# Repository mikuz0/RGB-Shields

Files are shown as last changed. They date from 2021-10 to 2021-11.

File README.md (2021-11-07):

# RGB-Shields
<p>RGB(W) шильд предназначен для создания прототипов и конечных устройств по управлению светодиодным освещением, совместно с Arduino nano.</p> 
</br>
<b>Основные характеристики: </b>

Напряжение питания: 12 в(ограничено Arduino nano) 

Выходной ток: не более 3 А на канал. 

Суммарный ток нагрузок не более 3 А. 

Количество независимых каналов: 4

Количество кнопок управления: 3

Возможность подключения ИК приёмника: да (приемник ИК сигнала vs1838)

Возможность программного контроля напряжения питания: да. 

Размеры габаритные: 60х49 мм

Размеры под винт: 52х38,4

3D модель: ссылка тут

Надписи с адресами подключения цепей на плате позволяют упростить создание программного обеспечения.

Демо ПО:

Есть пример, демонстрирующий основные возможности RGB(W) шильда. (<a href="https://github.com/mikuz0/RGB-Shields/tree/main/3d-print/models " >ссылка тут </a>) 

Пример предназначен только для проверки исправности RGB(W) шильда. 

Назначение кнопок в демоПО:

1. Переход на следующий режим

2. Увеличить яркость

3. Уменьшить яркость

Режимы демоПО:

1. Проверка совместной работы каналов. 

2. Проверка работы канала R. Остальные каналы закрыты. 

3. Проверка работы канала G.  Остальные каналы полностью закрыты. 

4. Проверка работы канала B. Остальные каналы полностью закрыты. 

5. Проверка работы канала W. Остальные каналы полностью закрыты. 

<b>Схема подключения RGBW-shield и данные для разработки програмного обеспечения.</b> <br>
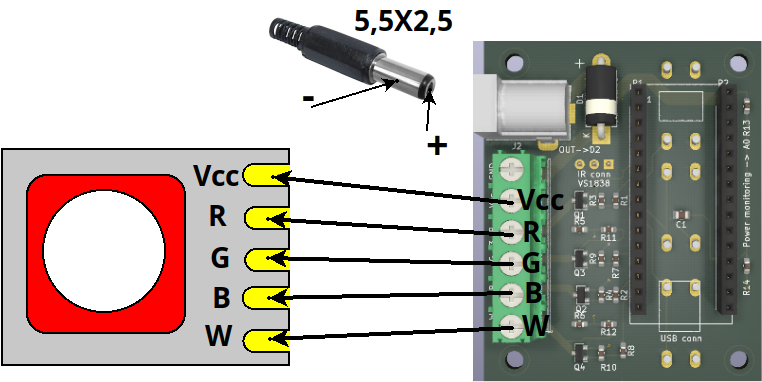
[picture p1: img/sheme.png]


<p>
Каналы R, G, B, W могут назначяться программно. В описании каналы обозначены в соответствии с предлагаемых ниже ПО. ПО не входит в поставку и предлагается как есть, без гарантий.
</p>

<p>
R - D3
</p>
<p>
G - D9
</p>
<p>
B - D10
</p>
<p>
W - D11
</p>

Каналы идентичный по нагрузочной способности.
VS1838 - D2
Кнопки D4, D5, D6  (см. маркировку на плате рядом с каждой кнопкой)

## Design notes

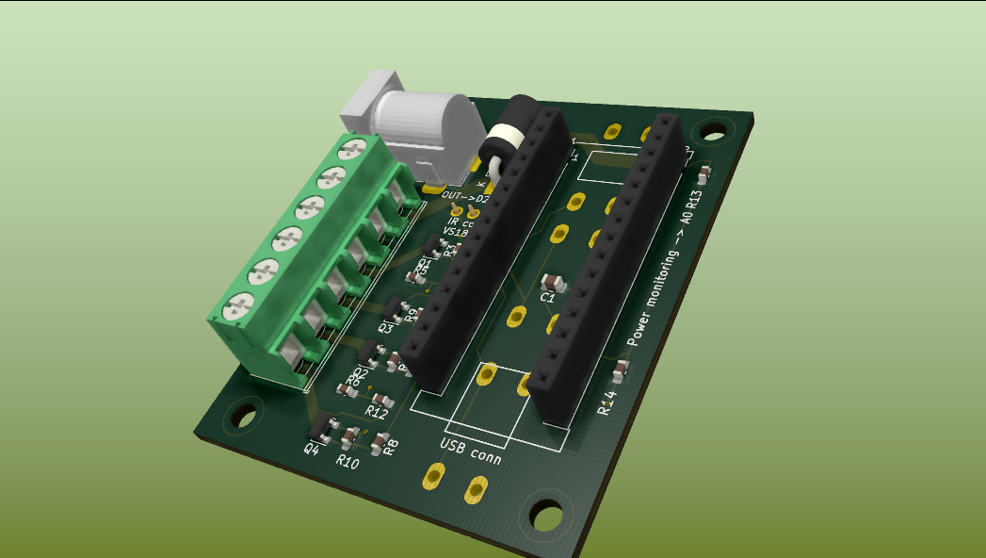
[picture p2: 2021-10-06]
screenshot_20210107_102106_0.png

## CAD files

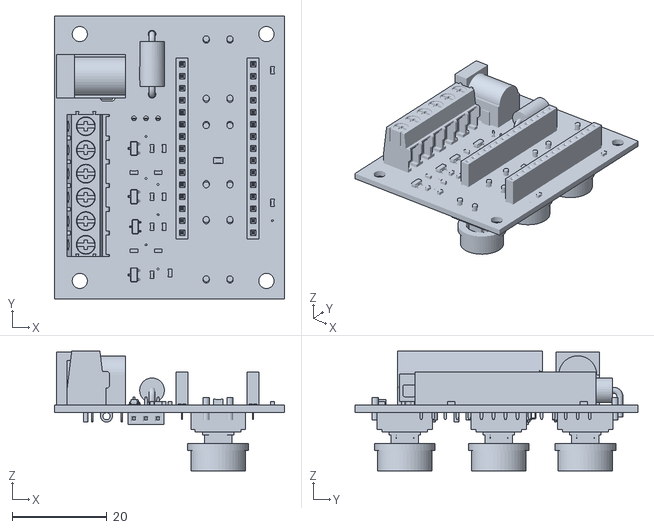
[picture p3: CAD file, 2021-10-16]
3d-print/ case/RGBschildSOT223.stl
48.5 x 59.7 x 25.3

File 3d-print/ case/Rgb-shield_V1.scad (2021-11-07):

//Enter OpenSCAD code here.
 echo("Version:",version());
r=100;
// Рисовать плату или нет.
PCB=1;
// размеры платы
A=48.26;
B=59.69;
H=25; //габаритная высота
S=1.5; // толщина текстолита
//размеры под винт
Av=39.37;
Bv=52.07;
Sm=5.5; // отступ отверстий от переднего края
Sb=3.81; // отступ отверстий с боков
//стойки для платы
Hp=7;
//толщина стенок
s=2;
//стойки для крышки
Ds=4;
Hs=H+s+S;
//размеры внутреннего объема
Aa=A+2;
Bb=B+2*Ds+2;

//радиус кнопки
Rp=6.5;
// Высота стоек под плату
Hss=11.6;
// стойка под крышку
module  rackb ( ) 
{ 

   
    difference() {
         union () {
cylinder (Hs, Ds/2, Ds/2, false, 
$fn=r);
     translate ([-s/3, -s/3, Hs/2+s/2]) 
 cube([Ds, Ds, Hs-s] , true, $fn=r);   
}       
        translate ([0, 0, 2*Hs/3]) 
  cylinder (Hs, 1.2, 1.2, false, 
$fn=r);      
    };

}
// стойка под плату
module  rack ( x=0,y=0) 
{   translate ([x, y, 0]) 
    difference() {
         
cylinder (Hss, Ds*0.8, 0.8*Ds, false, 
$fn=r);
    
      
        translate ([0, 0, 2*Hss/3]) 
  cylinder (Hss, 1.2, 1.2, false, 
$fn=r);      
    };

}

difference() {
union() 
{
 hull() {  translate([s, s, s])
  sphere(d=2*s, true, $fn=r);
   translate([Aa+2*s-s, s, s])
   sphere(d=2*s, true, $fn=r); 
   translate([Aa+2*s-s, Bb+2*s-s, s])
   sphere(d=2*s, true, $fn=r);  
     translate([s, Bb+2*s-s, s])
   sphere(d=2*s, true, $fn=r);  
    // Top
    translate([s, s, Hs])
   sphere(d=2*s, true, $fn=r);
   translate([Aa+2*s-s, s, Hs])
   sphere(d=2*s, true, $fn=r); 
 translate([Aa+2*s-s, Bb+2*s-s, Hs])
  sphere(d=2*s, true, $fn=r);  
   translate([s, Bb+2*s-s, Hs])
   sphere(d=2*s, true, $fn=r); 
  }

} ;
translate([s, s, s]) 
cube([Aa, Bb, Hs+4*s],$fn=r);

//отверстия под кнопки
Xk=34.18+0.42+s+0.5;
Yk=9.6+s+Ds+1+0.65;
Yk2=20.52;
translate ([Xk,Yk+Yk2+17.78,0])
cylinder (10, Rp, Rp, true, $fn=r);
translate ([Xk,Yk+Yk2,0])
cylinder (10, Rp, Rp, true, $fn=r);
translate ([Xk,Yk,0])
cylinder (10, Rp, Rp, true, $fn=r);
// Отверстия под питание
translate ([0,49.7,15])
cube([10, 10, 10],$fn=r);
translate ([0,19.7,20])
cube([10, 20, 5],$fn=r);
// отв. ИК приемник
translate ([s+0.5+16,Ds+s+1+27,0])
cube([6.1, 8.1, 10],$fn=r);
} 
// стойки для крышки
translate ([Ds/2+s, Ds/2+s, 0])
rackb ();
//rackb (0, 0, 0);
translate ([Aa-Ds/2+s, Ds/2+s, 0])
rotate([0,0,90]) 
rackb ();
translate ([Aa-Ds/2+s, Bb-Ds/2+s, 0])
rotate([0,0,180]) 
rackb ();
translate ([Ds/2+s, Bb-Ds/2+s, 0])
rotate([0,0,-90]) 
rackb ();

translate ([Sm+s+0.5,s+Sb+Ds+1,0]){
union (){
rack (0,0);
rack (0,52.07);
rack (39.37,52.07);
rack (39.37,0);
}
}
// Импорт платы
if (PCB==1)
    // 0.42 и 0.65 отступ 3 модели от нуля координат, 0.5 и 1 отступ от стенок
translate( [s+0.42+0.5, s+Ds+1+0.65, 12.5 ]){
difference () {
rotate([0,0,0]){#import ( "RGBschildSOT223.stl",  convexity = 5);}
 
 }
 }

// крышка
 module  vint ( x=0,y=0) 
{   translate ([x, y, -0.1]) 
    union() {
         
cylinder (s, 2.7, 0, false, 
$fn=r);
 
  cylinder (10, 1.6, 1.6, false, 
$fn=r);      
    };

}
 translate ([60,0,0])

 difference () {
cube([Aa-0.2, Bb-0.2, s],$fn=r);
vint (Ds, Ds);
vint (Aa-0.2-Ds, Ds);
vint (Aa-0.2-Ds, Bb-0.2-Ds);
vint (Ds, Bb-0.2-Ds);
 }

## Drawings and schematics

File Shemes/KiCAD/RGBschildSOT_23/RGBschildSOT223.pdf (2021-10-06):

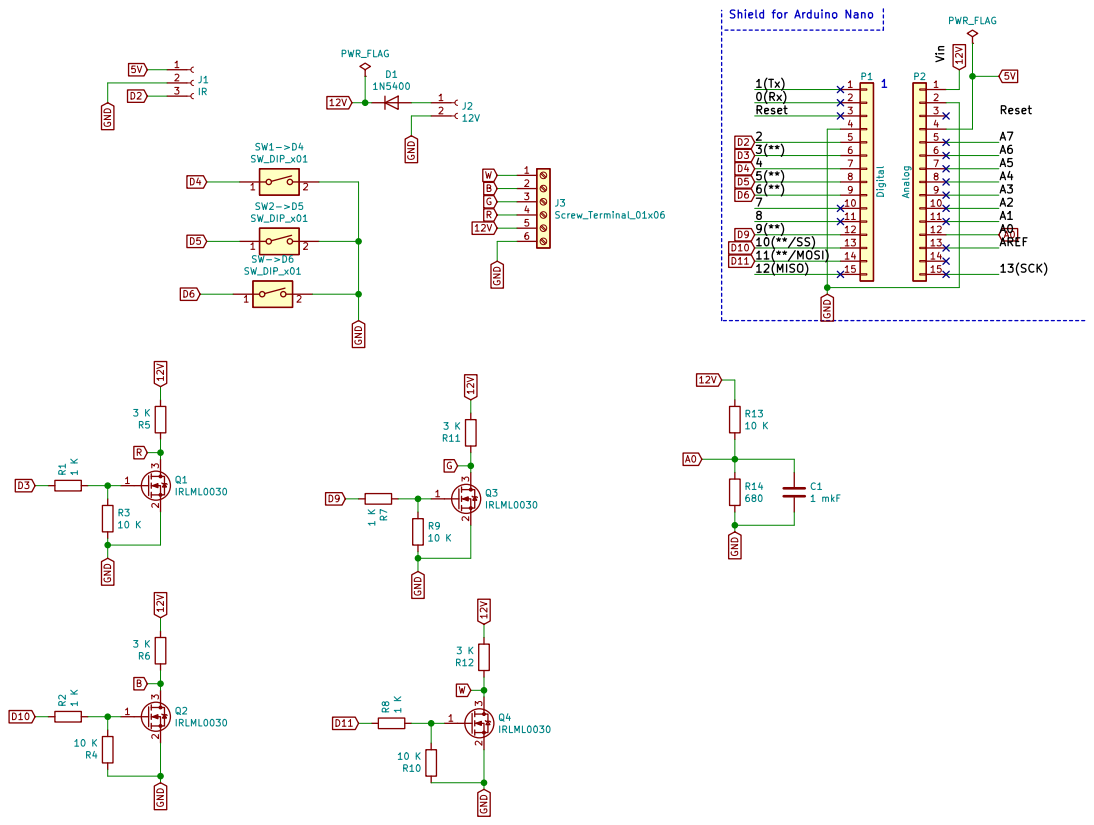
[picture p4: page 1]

Shield for Arduino Nano

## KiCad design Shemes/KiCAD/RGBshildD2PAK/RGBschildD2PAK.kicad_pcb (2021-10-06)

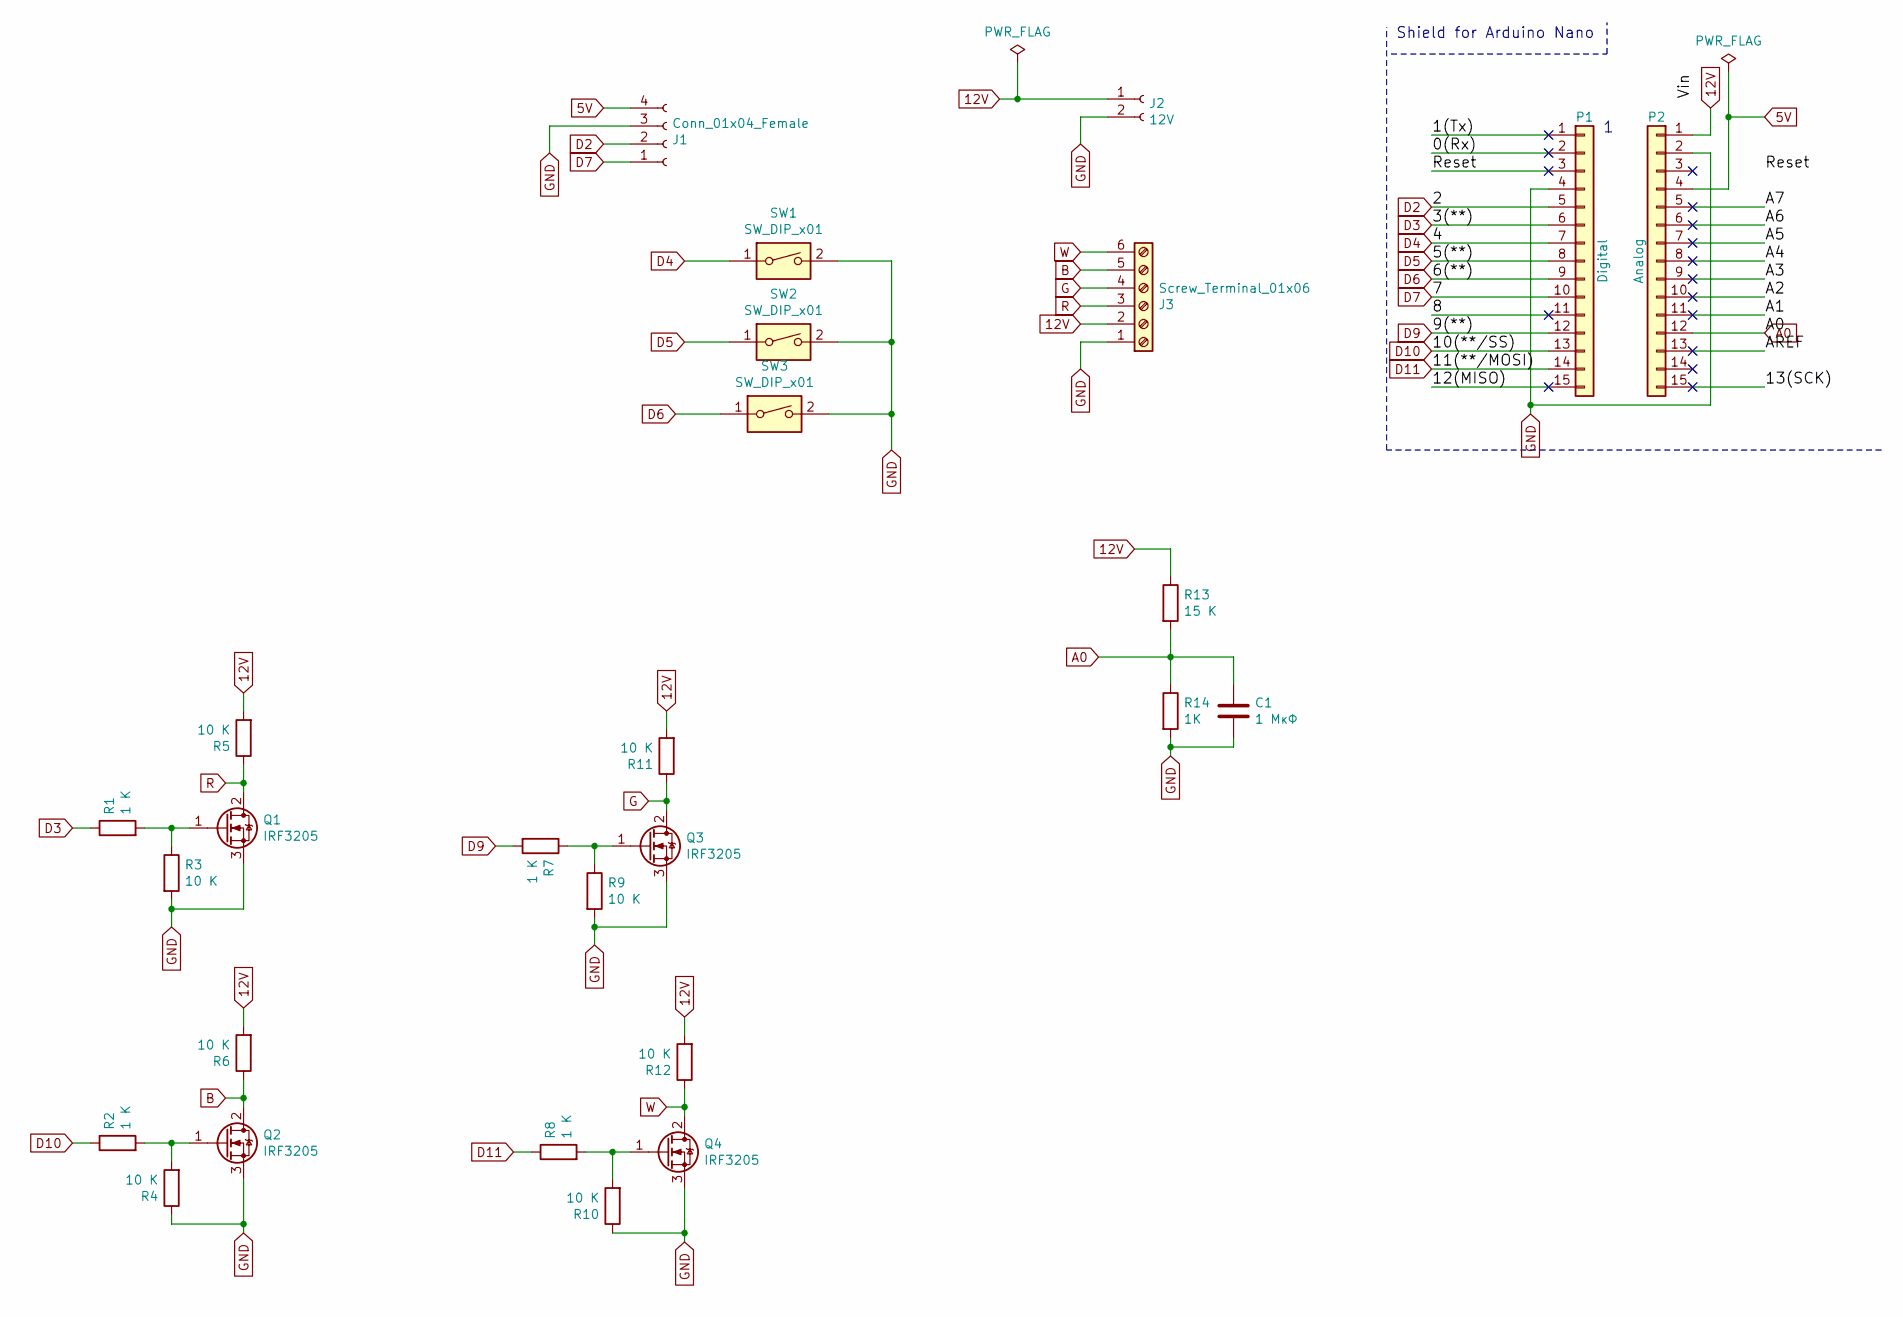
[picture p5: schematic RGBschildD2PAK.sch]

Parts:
C1: 1 МкФ; C_0805_2012Metric
J1: Conn_01x04_Female; PinSocket_1x04_P2.54mm_Vertical
J2: 12V; BarrelJack_Horizontal
J3: Screw_Terminal_01x06; TerminalBlock_Phoenix_PT-1,5-6-5.0-H_1x06_P5.00mm_Horizontal
P1: Digital; PinSocket_1x15_P2.54mm_Vertical
P2: Analog; PinSocket_1x15_P2.54mm_Vertical
Q1, Q2, Q3, Q4: IRF3205; D2PAK_12
R1, R2, R7, R8: 1 K; C_0603_1608Metric_Pad1.08x0.95mm_HandSolder
R3, R4, R5, R6, R9, R10, R11, R12: 10 K; C_0603_1608Metric_Pad1.08x0.95mm_HandSolder
R13: 15 K; C_0603_1608Metric_Pad1.08x0.95mm_HandSolder
R14: 1K; C_0603_1608Metric_Pad1.08x0.95mm_HandSolder
SW1, SW2, SW3: SW_DIP_x01; SW_PUSH-12mm

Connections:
5V: J1.4, P2.4
12V: J2.1, J3.2, P2.1, R5.2, R6.2, R11.2, R12.2, R13.1
/0(Rx): P1.2
/1(Tx): P1.1
/8: P1.11
/12(MISO): P1.15
/13(SCK): P2.15
/A1: P2.11
/A2: P2.10
/A3: P2.9
/A4: P2.8
/A5: P2.7
/A6: P2.6
/A7: P2.5
/AREF: P2.13
/Reset: P1.3
A0: C1.1, P2.12, R13.2, R14.1
B: J3.5, Q2.2 (D), R6.1
D2: J1.2, P1.5
D3: P1.6, R1.1
D4: P1.7, SW1.1
D5: P1.8, SW2.1
D6: P1.9, SW3.1
D7: J1.1, P1.10
D9: P1.12, R7.2
D10: P1.13, R2.1
D11: P1.14, R8.1
G: J3.4, Q3.2 (D), R11.1
GND: C1.2, J1.3, J2.2, J3.1, P1.4, P2.2, Q1.3 (S), Q2.3 (S), Q3.3 (S), Q4.3 (S), R3.2, R4.1, R9.2, R10.1, R14.2, SW1.2, SW2.2, SW3.2
unnamed: Q1.1 (G), R1.2, R3.1
unnamed: Q2.1 (G), R2.2, R4.2
unnamed: Q3.1 (G), R7.1, R9.1
unnamed: Q4.1 (G), R8.2, R10.2
R: J3.3, Q1.2 (D), R5.1
W: J3.6, Q4.2 (D), R12.1

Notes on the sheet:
Shield for Arduino Nano

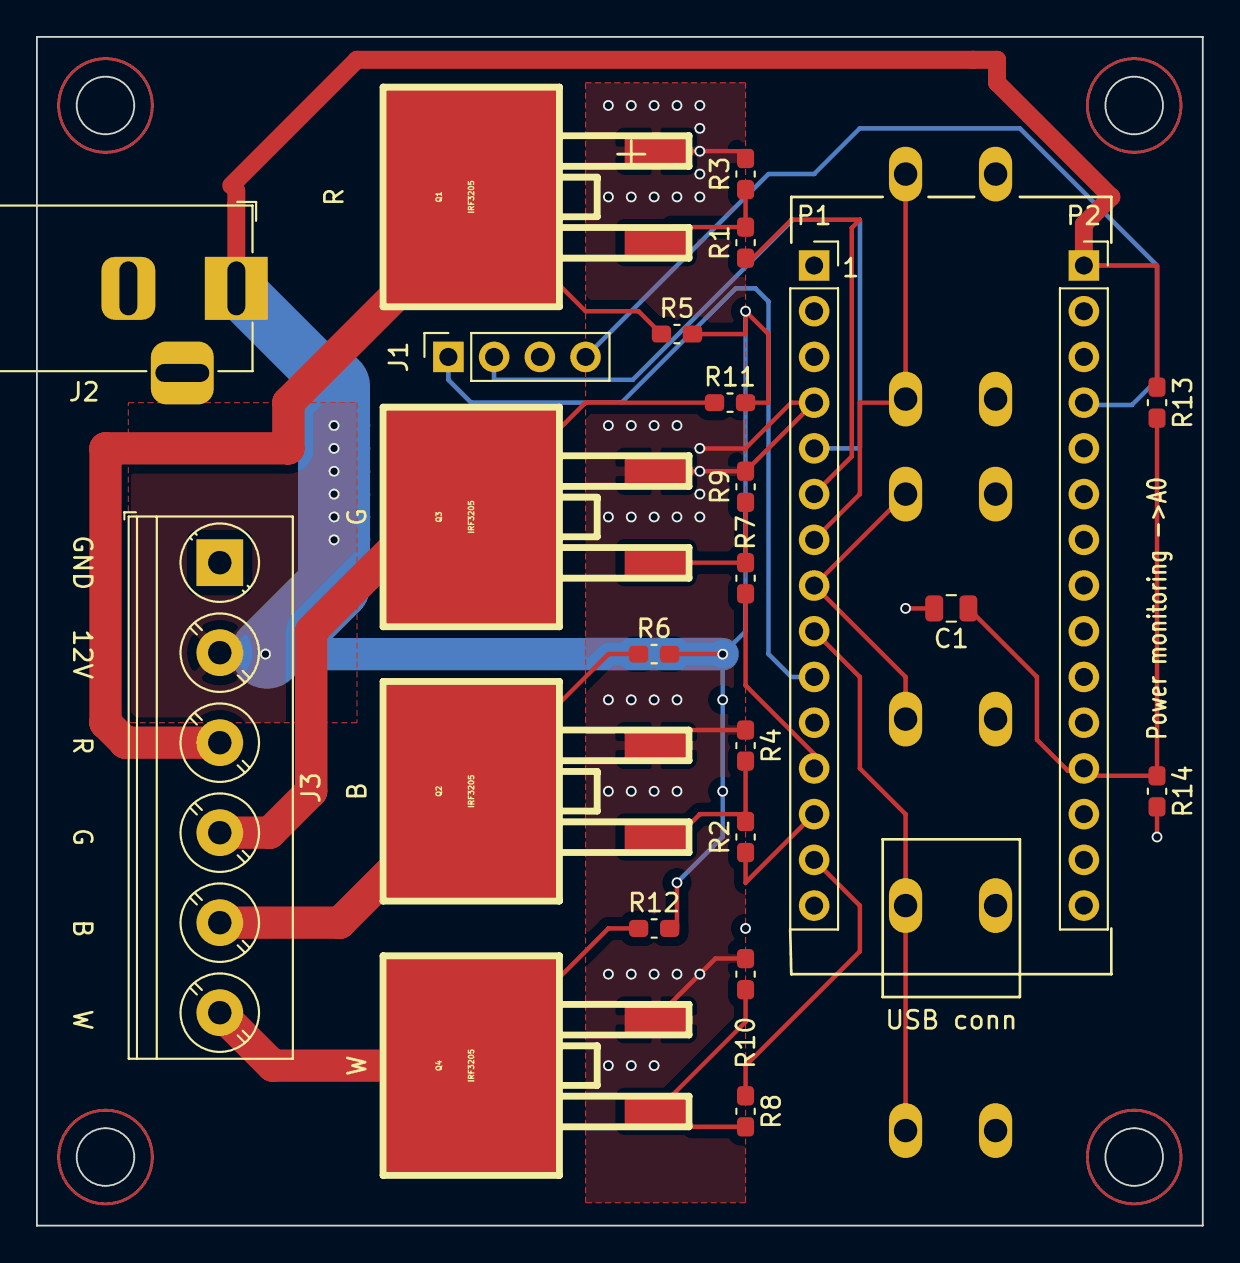
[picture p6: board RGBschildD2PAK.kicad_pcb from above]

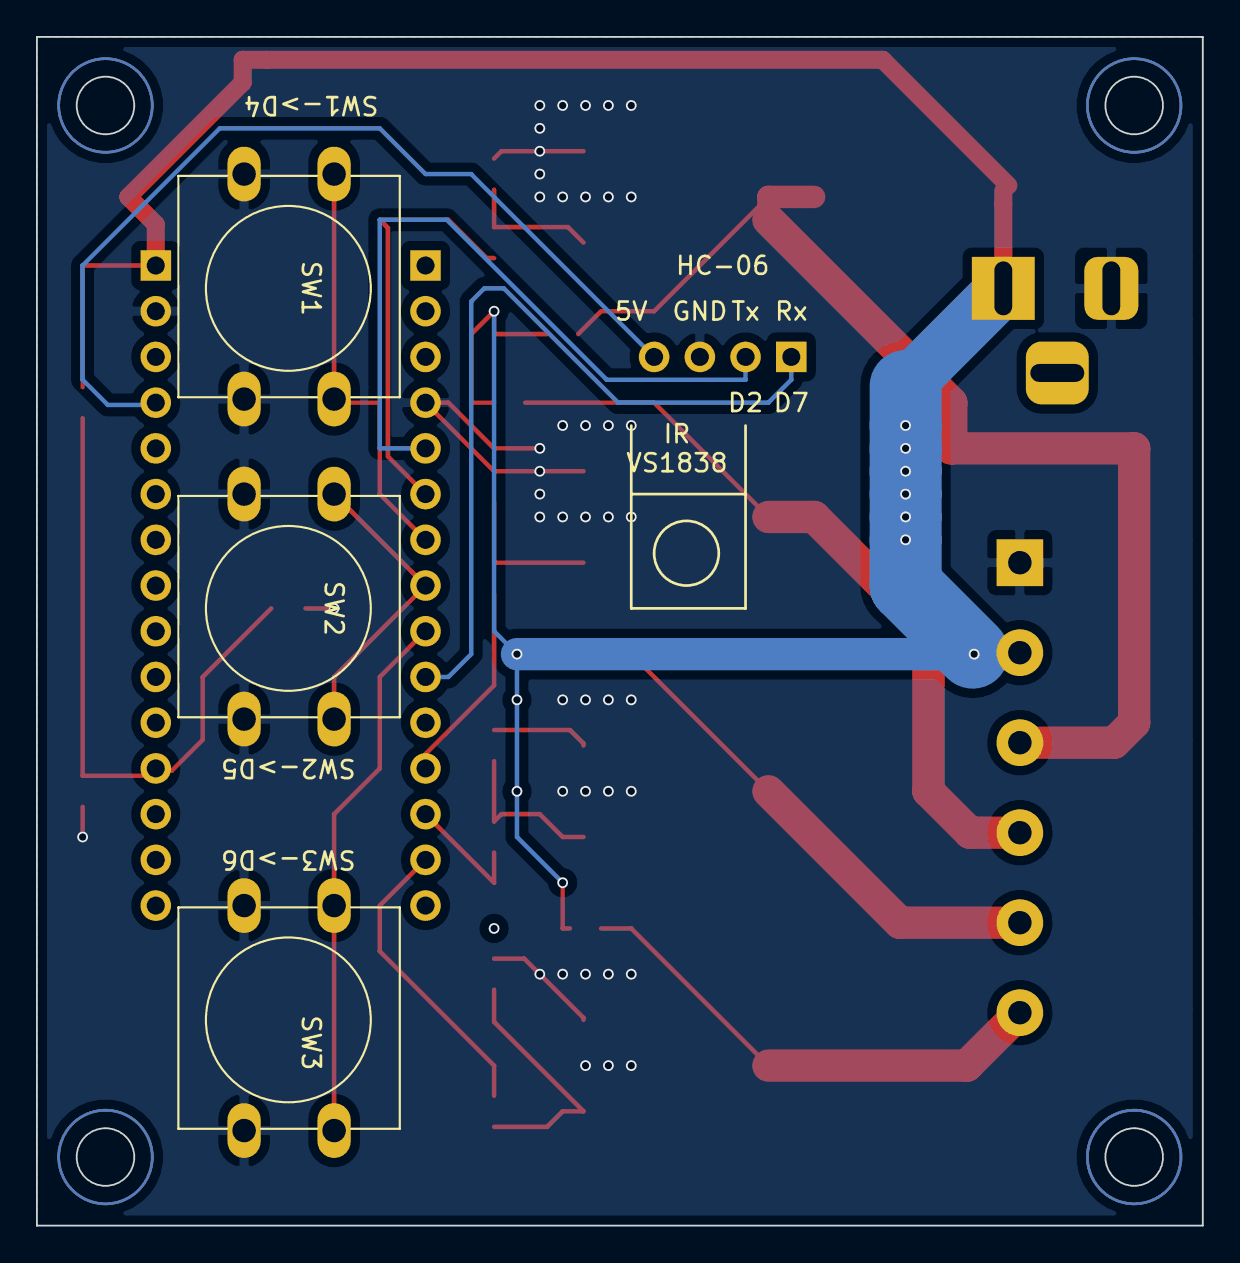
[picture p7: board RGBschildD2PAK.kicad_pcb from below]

Board: 2 copper layers, 64.8 x 66.0 mm, 27 parts (3 on the bottom side), 21 nets.

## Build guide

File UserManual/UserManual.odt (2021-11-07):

## Руководство пользователя

## RGBW-shield

1.Назначение.

2. Характеристики.

3. Комплектность.

4. Схема подключения.

5. Ссылки на ресурсы. Гитхаб.Проект и тестовое ПО.

### 1.Назначение

RGB(W) шильд предназначен для создания прототипов и конечных устройств по управлению светодиодным освещением, совместно с Arduino nano.

### 2. Основные характеристики:

Напряжение питания: 12 в(ограничено Arduino nano)

Выходной ток: не более 3 А на канал.

Суммарный ток нагрузок: не более 3 А.

Количество независимых каналов: 4

Количество кнопок управления: 3

Возможность подключения ИК приёмника: да (приемник ИК сигнала vs1838)

Возможность программного контроля напряжения питания: да.

Типы подключаемых RGBW лент:

В соответствии с поданным питанием 5-12 В.

Только с общим питанием. (см. Схему подключения)

Размеры габаритные: 60х49 мм

Размеры под винт: 52х38,4

См. 3D модель в проекте. Ссылка тут. (https://github.com/mikuz0/RGB-Shields/tree/main/3d-print/models)

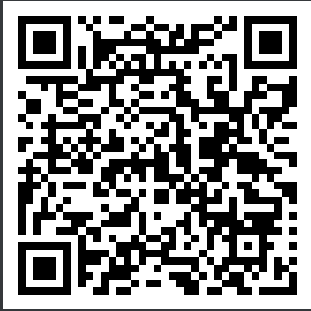
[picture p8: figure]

Демо ПО:

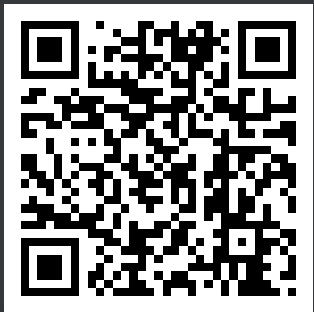
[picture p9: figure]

Есть пример, демонстрирующий основные возможности RGB(W) шильда.

Пример предназначен только для проверки исправности RGB(W) шильда.

Назначение кнопок в демоПО:

1. Переход на следующий режим

2. Увеличить яркость

3. Уменьшить яркость

Режимы демоПО:

1. Проверка совместной работы каналов.

2. Проверка работы канала R. Остальные каналы закрыты.

3. Проверка работы канала G. Остальные каналы полностью закрыты.

4. Проверка работы канала B. Остальные каналы полностью закрыты.

5. Проверка работы канала W. Остальные каналы полностью закрыты.

### 3. Комплектность.

RGBW-SHIELD - 1шт

Описание - 1 шт

ИК приемник- под заказ

Arduino nano – под заказ

Разьем питания- под заказ

### 4.Схема подключения RGBW-shield и данные для разработки програмного обеспечения.


Каналы R, G, B, W могут назначяться программно. В описании каналы обозначены в соответствии с предлагаемых ниже ПО. ПО не входит в поставку и предлагается как есть, без гарантий.

R - D3

G - D9

B - D10

W - D11

Каналы идентичный по нагрузочной способности.

VS1838 - D2

Кнопки D4, D5, D6 (см. маркировку на плате рядом с каждой кнопкой)

### 5. Ссылки на ресурсы.

Проект на ГитХабе:

https://github.com/mikuz0/RGB-Shields

Тестовое ПО на ГитХабе:

https://github.com/mikuz0/RGB_shild_test_PIO

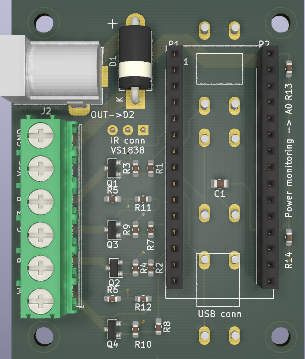
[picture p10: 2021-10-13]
UserManual/RGBschild.png

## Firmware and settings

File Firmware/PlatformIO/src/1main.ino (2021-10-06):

#include <Arduino.h>
// ------ Драйвер ------
#define HIGH_FREQUENCY 1    // 0 - 490 Гц, 1 - 7.8 кГц, 2 - 31.4 кГц, 3 - ручная настройка
#define PWM_FREQUENCY 15000 // частота ШИМ на настройке №3, Герц
#define DRIVER_DIRECTION 0  // 0 - обычный (мосфеты), 1 - реверс (LED amplifier)

#define USE_LOG 1
#define R13 10.0
#define R14 0.670

// Включить поддержку BT 1
#define USE_BT 0

// Включить поддержку IR 1
#define USE_IR 1

#if (USE_IR == 1)
#define IR_PIN 2 // указываем вывод, к которому подключен приемник

#include "IRLremote.h"
CHashIR IRLremote;
uint32_t IRdata;
#define BUILTIN 13 // светодиод для мигания с пульта
#endif

// ------ Кнопка -------
#define USE_BTN 1           // 1 - использовать кнопку, 0 - нет
// #define BTN_MODE 0          // режим работы кнопки: 0 - переключение пресетов, 1 - переключение цветов
//
// кнопка 4, 5- парные, 6- Отдельная
#define BTN_1 6
#define BTN_2 4
#define BTN_3 5

// --------- Цвет ---------
#define MIN_PWM 0           // минимальный сигнал PWM
// #define GAMMA_BRIGHT 1      // гамма-коррекция яркости
// #define LUT_R 1.0           // коэффициент LUT матрицы красного цвета (0.0 - 1.0)
// #define LUT_G 1.0           // коэффициент LUT матрицы зелёного цвета (0.0 - 1.0)
// #define LUT_B 1.0           // коэффициент LUT матрицы синего цвета (0.0 - 1.0)

// драйвер
#define PIN_R 3
#define PIN_G 9
#define PIN_B 10
#define PIN_W 11


#define LED_PIN 13 // светодиод
//Колличество режимов
#define N_eff 4
#define N_contr 4
//#define EPROM_CONTR 98 // для очистки памяти поменять на другое



//#include <EEPROMex.h>
#include <GyverRGB.h>
GRGB diode(PIN_R, PIN_G, PIN_B);  // куда подключены цвета (R, G, B)

#include <GyverButton.h>
GButton btn(BTN_1);
GButton btn2(BTN_2);
GButton btn3(BTN_3);


int8_t eff=0 ; // режим вывода
byte contr=1 ; // режим управления энкодором, что меняем
int  Brightness = 250; // яркость белого канала
int  BrightnessRGB =250 ;
byte  H = 150;
byte  S = 200;
int  V = 230;
byte  H_min=0;
byte  H_max=250;
byte  S_min=150;
byte  S_max=255;
int Temp=1010;
float Tcollor_min=10;
float Tcollor_max=100;
// настройки режимов
float speedK_min=10 ;// длительность цикла мС
float speedK_max=100;
byte  R=200;
byte  G=50;
byte  B=70;
uint32_t Timer=0, TimerR=0, TimerG=0, TimerB=0;
float speedTemp=500; // 100 - 1000

int Color=0 ;

bool napr=true ;
bool naprS=true ;

bool naprSp=false;
bool hdiod=true;
bool eeprom_wr=false;
byte P_svdiod=0;
bool btnControl = true;
bool LEDon = true;
byte xx=1;

void setup() {
  #if (USE_IR == 1)
 IRLremote.begin(IR_PIN); // запускаем прием
 
  pinMode(BUILTIN, OUTPUT);
#endif
  analogReference(INTERNAL);
  //analogReference(EXTERNAL);
   if (USE_LOG) Serial.begin(9600);
  // инициализируем светодиод и показиваем что питание есть
  pinMode(LED_PIN, OUTPUT);
  digitalWrite(LED_PIN, HIGH);
  // put your setup code here, to run once:
  //pinMode(PIN_R, OUTPUT);
  //pinMode(PIN_G, OUTPUT);
  //pinMode(PIN_B, OUTPUT);
  pinMode(PIN_W, OUTPUT);
  //diode.setMinPWM(MIN_PWM);

// btn.setStepTimeout(150);
btn.setClickTimeout(500);
btn2.setClickTimeout(500);
btn3.setClickTimeout(500);  

 // ------ ЛЕНТА -------
  // выставляем режим и частоту ШИМ
  if (HIGH_FREQUENCY == 1) {
    TCCR1B |= _BV(WGM12);
    TCCR1B = TCCR1B & 0b11111000 | 0x02;
    TCCR2A |= _BV(WGM20) | _BV(WGM21);
    TCCR2B = TCCR2B & 0b11111000 | 0x02;
  } else if (HIGH_FREQUENCY == 2) {
    TCCR1B &= ~_BV(WGM12);
    TCCR1B = TCCR1B & 0b11111000 | 0x01;
    TCCR2A |= _BV(WGM20);
    TCCR2B = TCCR2B & 0b11111000 | 0x01;
  } else if (HIGH_FREQUENCY == 3) {
    diode.highFrequency(PWM_FREQUENCY);
  }
#if (USE_LOG == 1)
Serial.println("Start devis");
#endif
 
}

void loop() {
  
 if (btnControl ) controlTick();    // отработка управления если не блокировано ВТ
 if (LEDon ) effectsTick(); else {
    digitalWrite(PIN_R, LOW);
    digitalWrite(PIN_G, LOW);
    digitalWrite(PIN_B, LOW);
    digitalWrite(PIN_W, LOW); }    // вывод режимов если не выключено
#if (USE_BT == 1)
bluetoothTick();
#endif
sv_diod();
#if (USE_LOG == 1)
LogTick();
#endif
  #if (USE_IR == 1)
IRtick();
#endif
}
